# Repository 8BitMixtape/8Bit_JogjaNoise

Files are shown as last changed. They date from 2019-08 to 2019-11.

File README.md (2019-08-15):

# 8Bit NoiseBomb - Jogjarmageddon

8Bit Mixtape goes minimal stompbox style for simple NoiseBomb!!

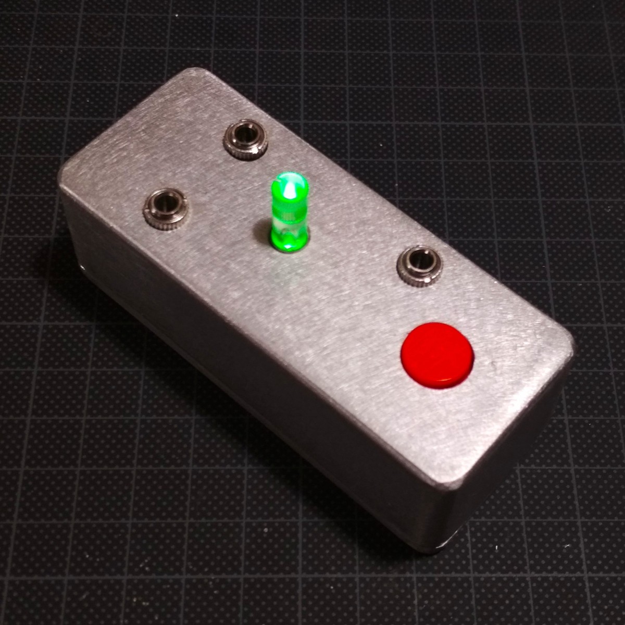
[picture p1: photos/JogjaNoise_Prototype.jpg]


It is a lo-fi 8Bit noise synthesizer based on the Arduino-compatible ATTINY85, featuring 1 Pot, 1 Button and a single LED inside the potentiometer shaft. Multiple NoiseBombs can be connected to each other using CV input/output and synced to other standard gear (KORG, Pocket Operators and more).

# Features

## New Bootloader for instant Noise

The key feature of the new 8Bit NoiseBomb is the easiness of uploading new codes using an audio communication protocol, means just playing a .wav sound file from your computer/smart phone (or walkman). Adjust volume to 50-70% if you encounter troubles during upload.

See more about this super powerful and easy-to-use TinyAudioBoot by Christoph Haberer here:
https://github.com/ChrisMicro/TinyAudioBoot

## Blinke Potentiometer

## 1 x CV input

## 1 Push Button

## diversity of Jacks 3.5 and 6.5 option

# PCB

We tried to create a PCB design that fits into a Hammond 1590A box, but also can be used stand-alone, and etched by hand single sided.

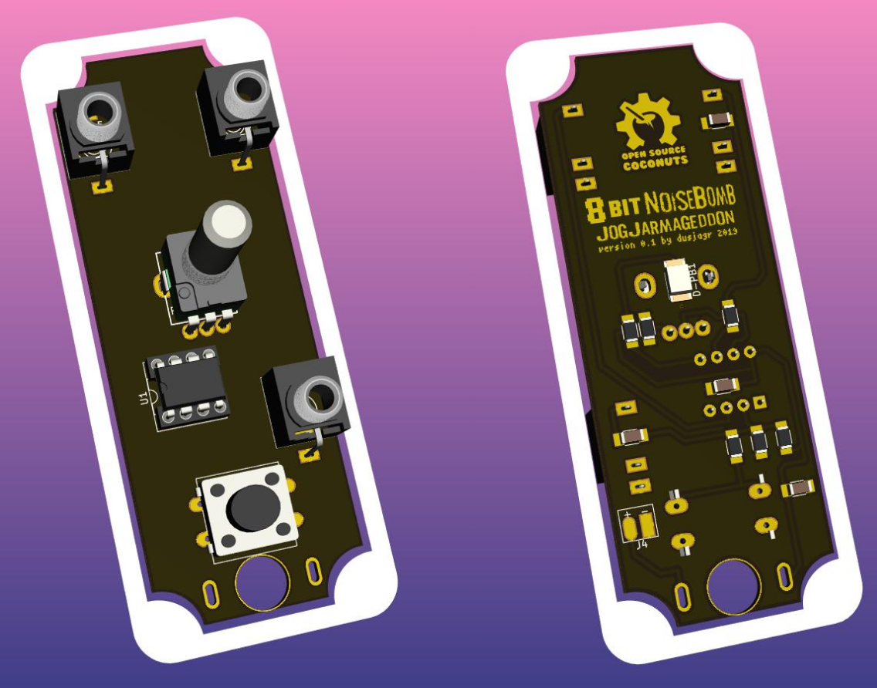
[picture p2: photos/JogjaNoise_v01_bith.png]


# Schematic

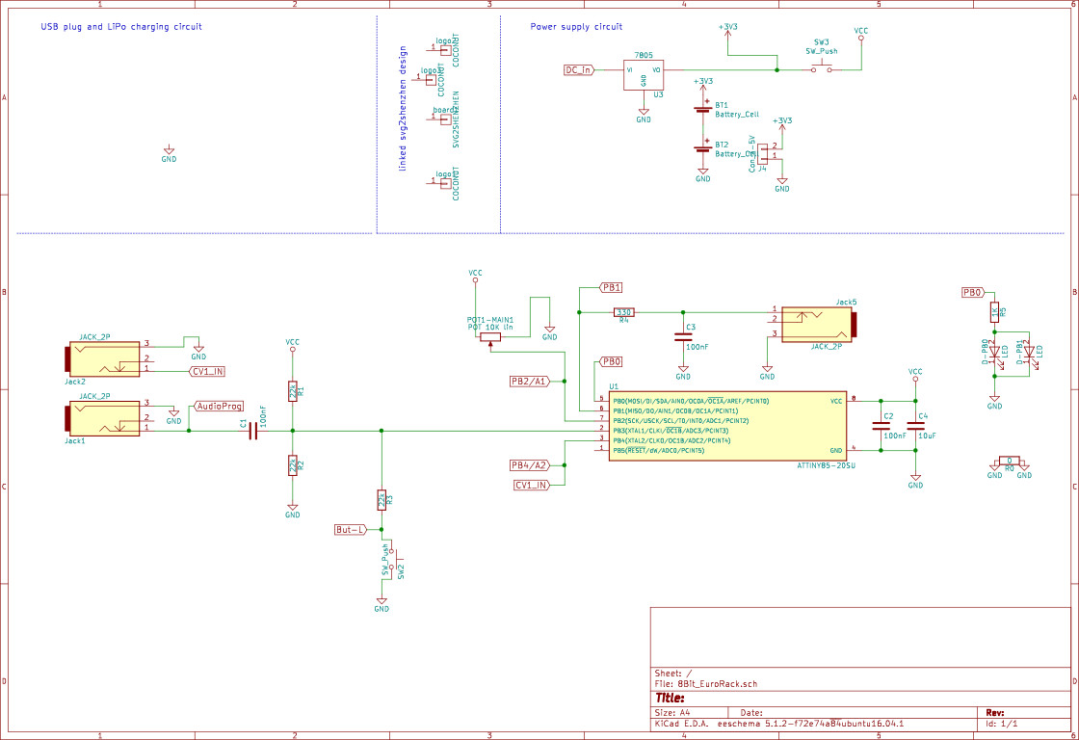
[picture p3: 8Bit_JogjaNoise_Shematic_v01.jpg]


# Sound / Noise Software

## Community contributions

Choose from a large collection of community contributed [Sequencers, Noise Generators & Synths](http://neo.8bitmixtape.cc/mixtape).

## Dedicated NoiseCodes

We have adapted other open source NoiseCodes to work on this little NoiseBomb, such as:

* Jogjarmageddon - based on [Mozenzeef's Jarmageddon](https://www.moffenzeefmodular.com/jarmaggeddon)
* QuantumNoise - based on [Alexander Zolotov's QuantumDJ](http://warmplace.ru/hard/qdj/)
* Adaptations from the [ATTINY PUNK CONSOLE by Steffen Koritsch](https://noisio.de/)
* Various Synths from the [8Bit Mixtape Community, especially by Budi Prakosa](http://neo.8bitmixtape.cc/mixtape)

## Write your own NoiseCode

Create your own custom synthesizers or filter using the popular Arduino IDE platform. Many examples help you to learn about DDS (Direct Digital Synthesis) using the 8Bit microcontroller ATTINY85.

Install the 8Bit Mixtape hardware in your Arduino IDE following the [instruction from the 8Bit Mixtape wiki](http://wiki.8bitmixtape.cc/)

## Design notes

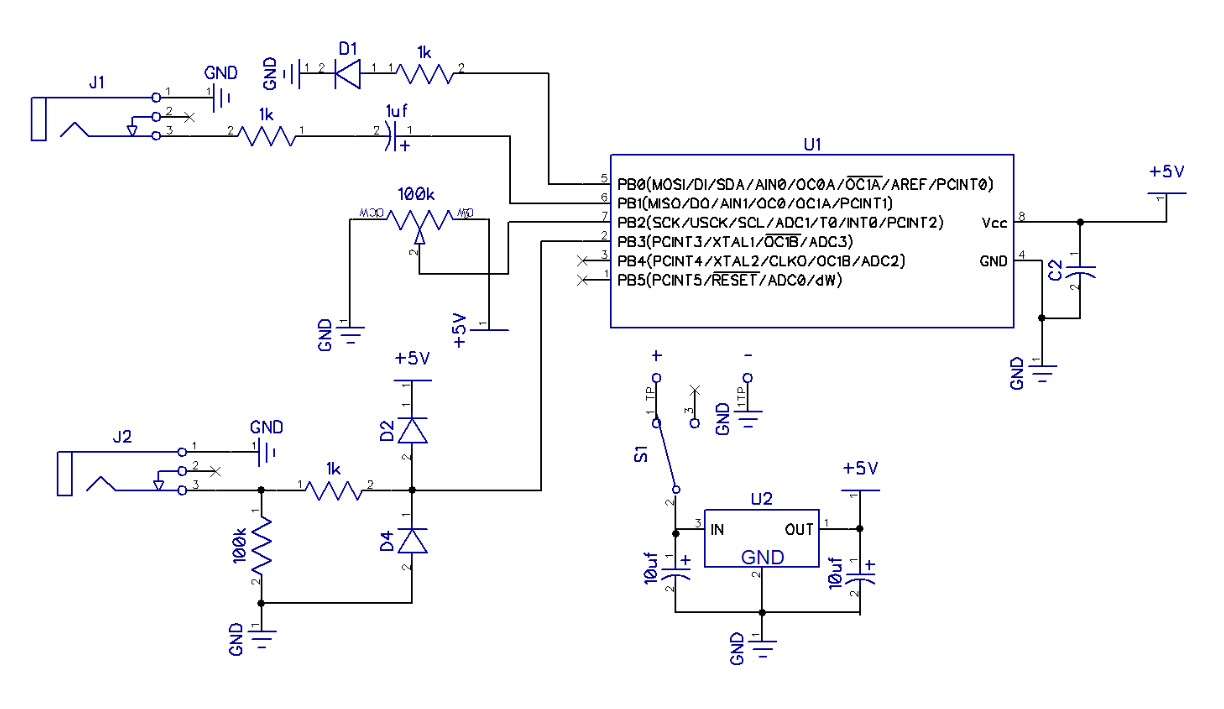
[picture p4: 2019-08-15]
photos/jarmageddon_schematics.png

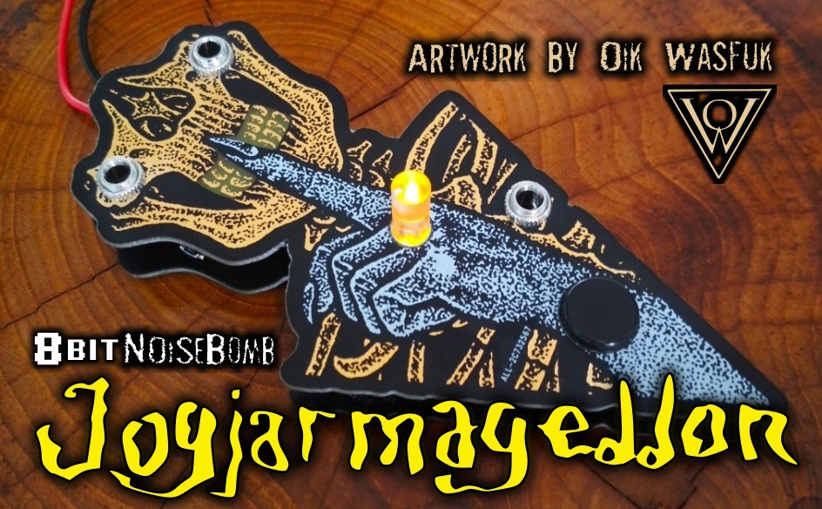
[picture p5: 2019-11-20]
photos/Jogjarmageddon_Product.jpg

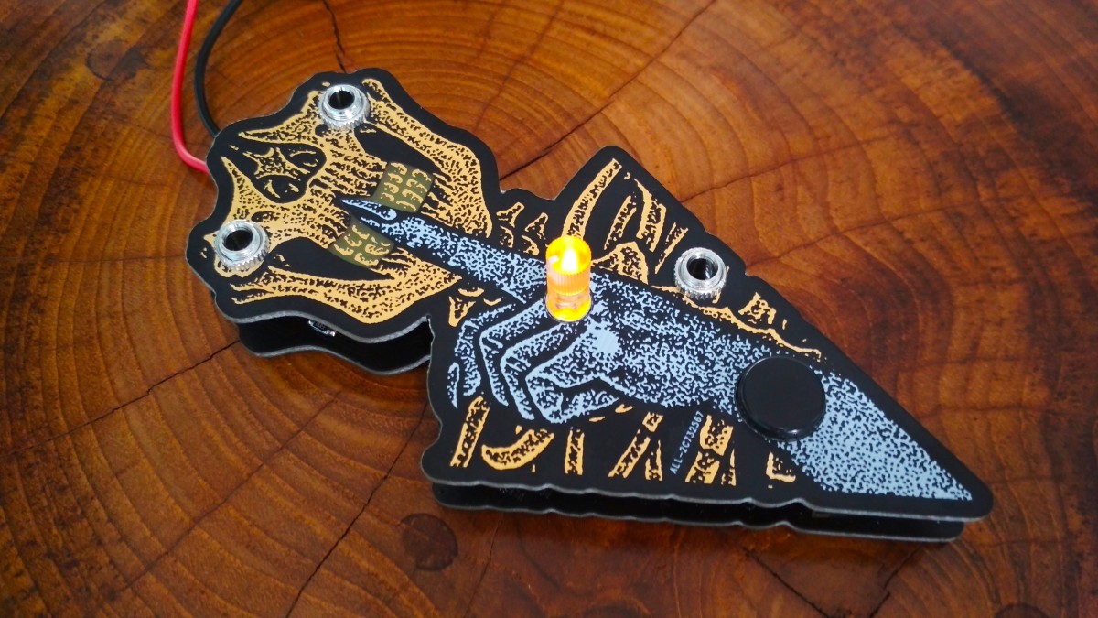
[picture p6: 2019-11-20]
photos/NoiseBomb_Oik_side.jpg

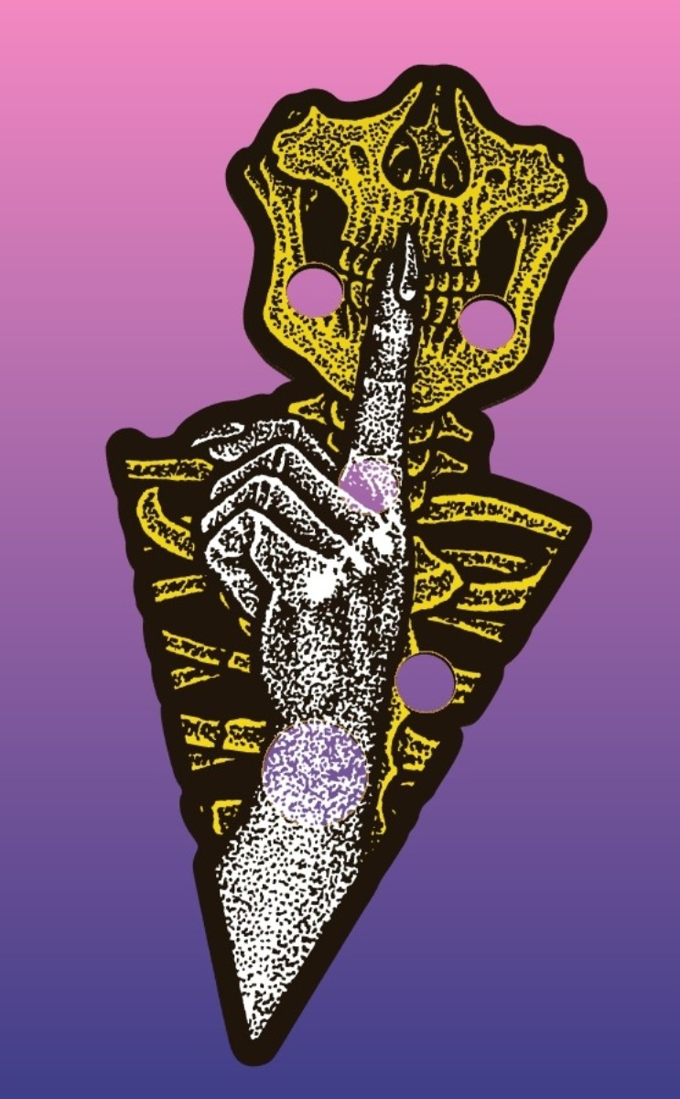
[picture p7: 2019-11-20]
photos/Jogjarmageddon_pcb.jpg

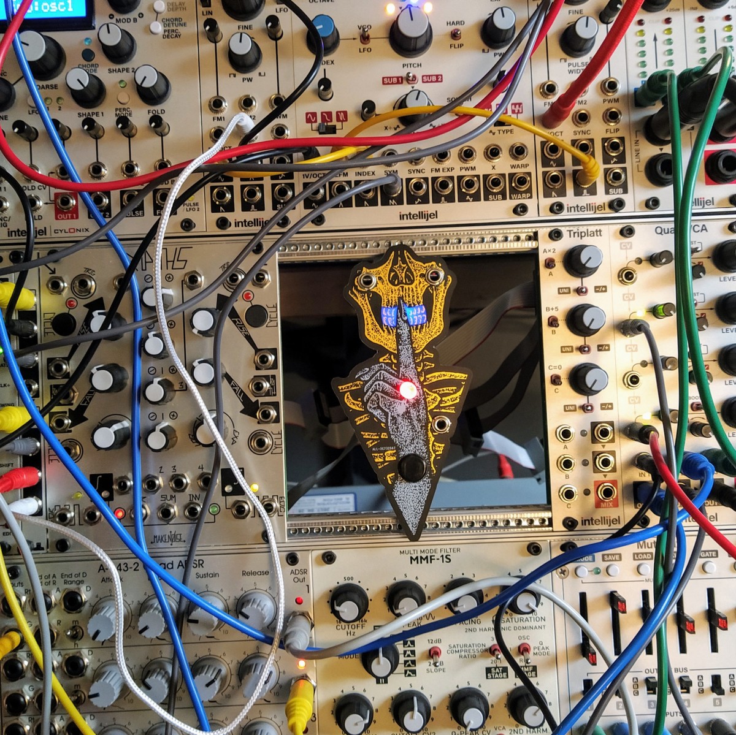
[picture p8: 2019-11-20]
photos/Jogjarmageddon_in_modular.jpg

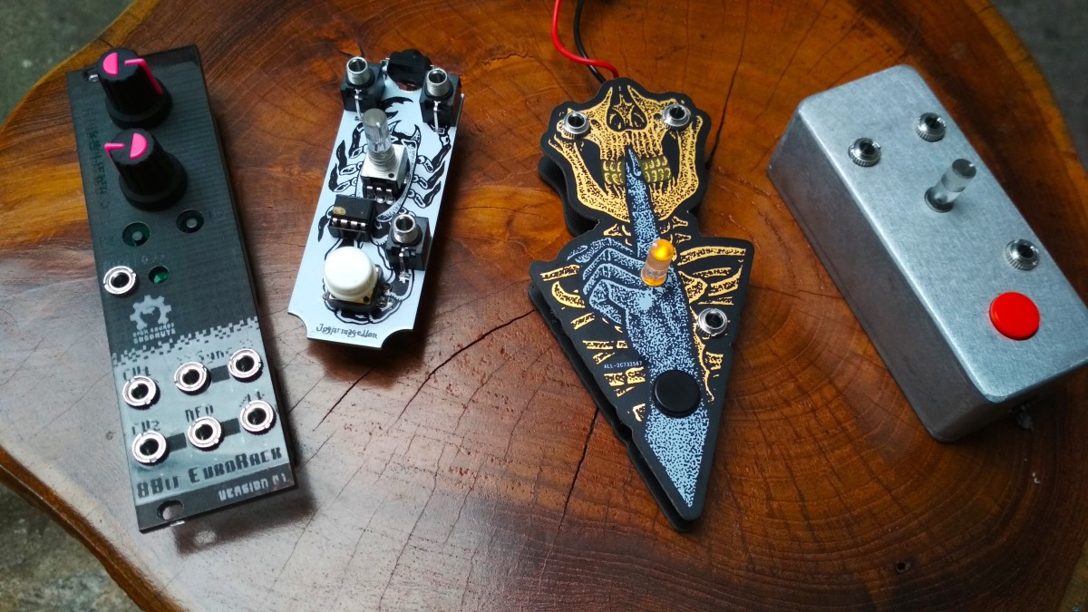
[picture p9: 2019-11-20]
photos/JogjaNoise_NewFamily_8BitMixtape.jpg

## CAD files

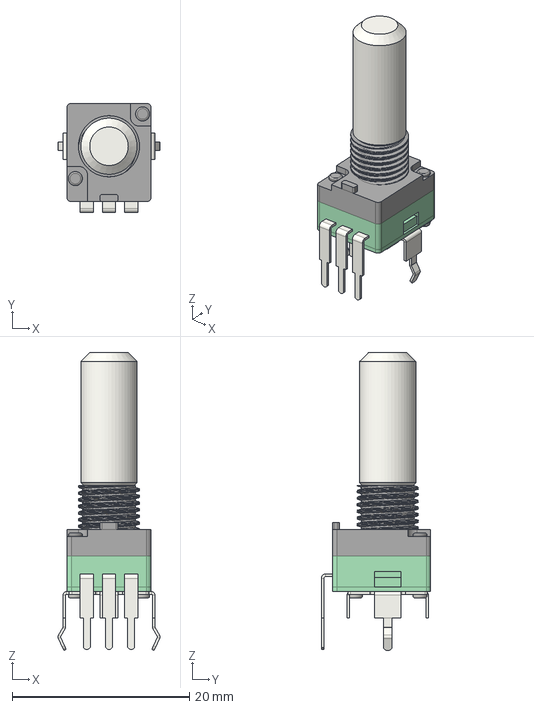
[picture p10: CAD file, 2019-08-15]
KiCAD/3d_models/ALPHA-RD901F-40.step
11.5 x 12.4 x 33.6 mm

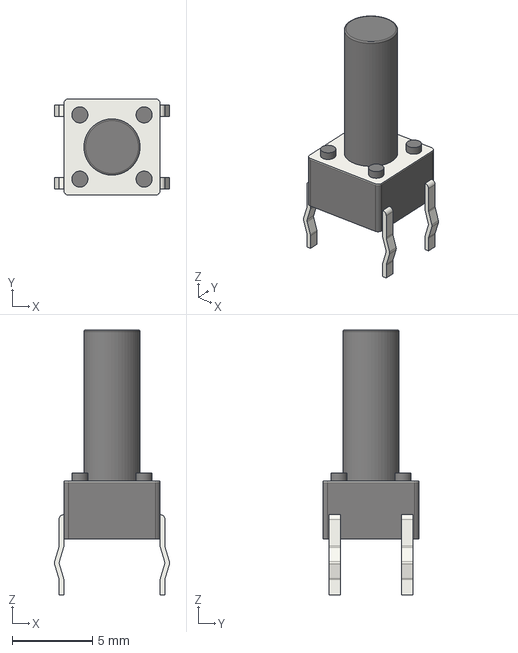
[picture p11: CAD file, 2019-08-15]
KiCAD/3d_models/SW_PUSH_6mm_H13mm.step
7.17 x 6.00 x 16.5 mm

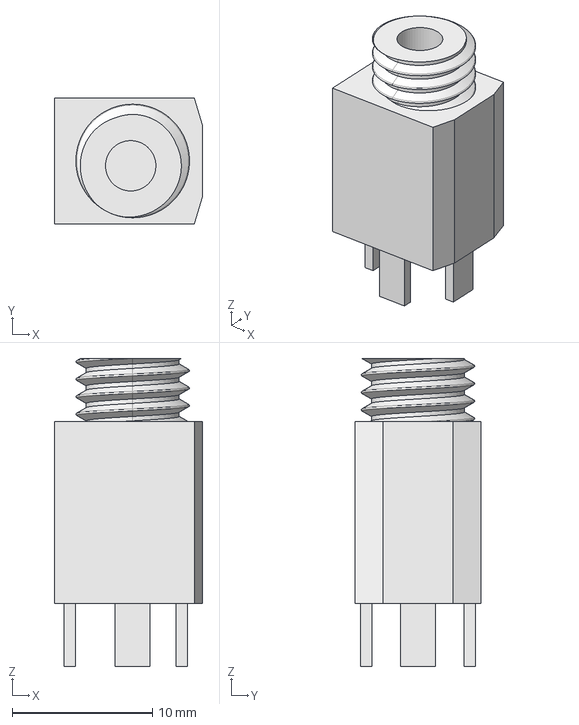
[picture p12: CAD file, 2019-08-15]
KiCAD/3d_models/PJ3410.step
10.6 x 9.00 x 22.0 mm

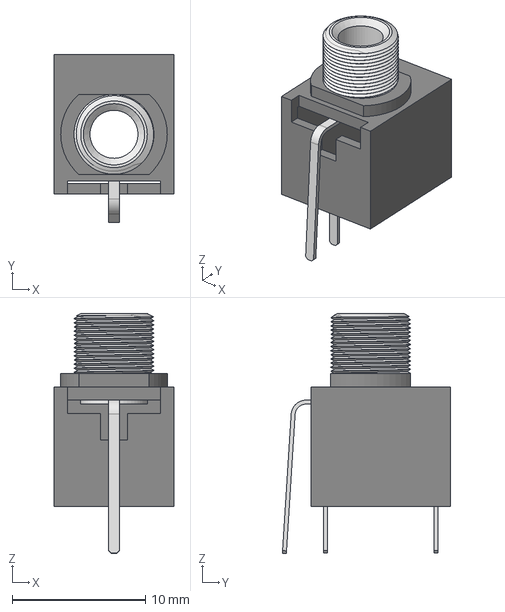
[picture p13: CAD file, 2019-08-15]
KiCAD/3d_models/PJ301M-12.step
9.00 x 12.6 x 18.0 mm

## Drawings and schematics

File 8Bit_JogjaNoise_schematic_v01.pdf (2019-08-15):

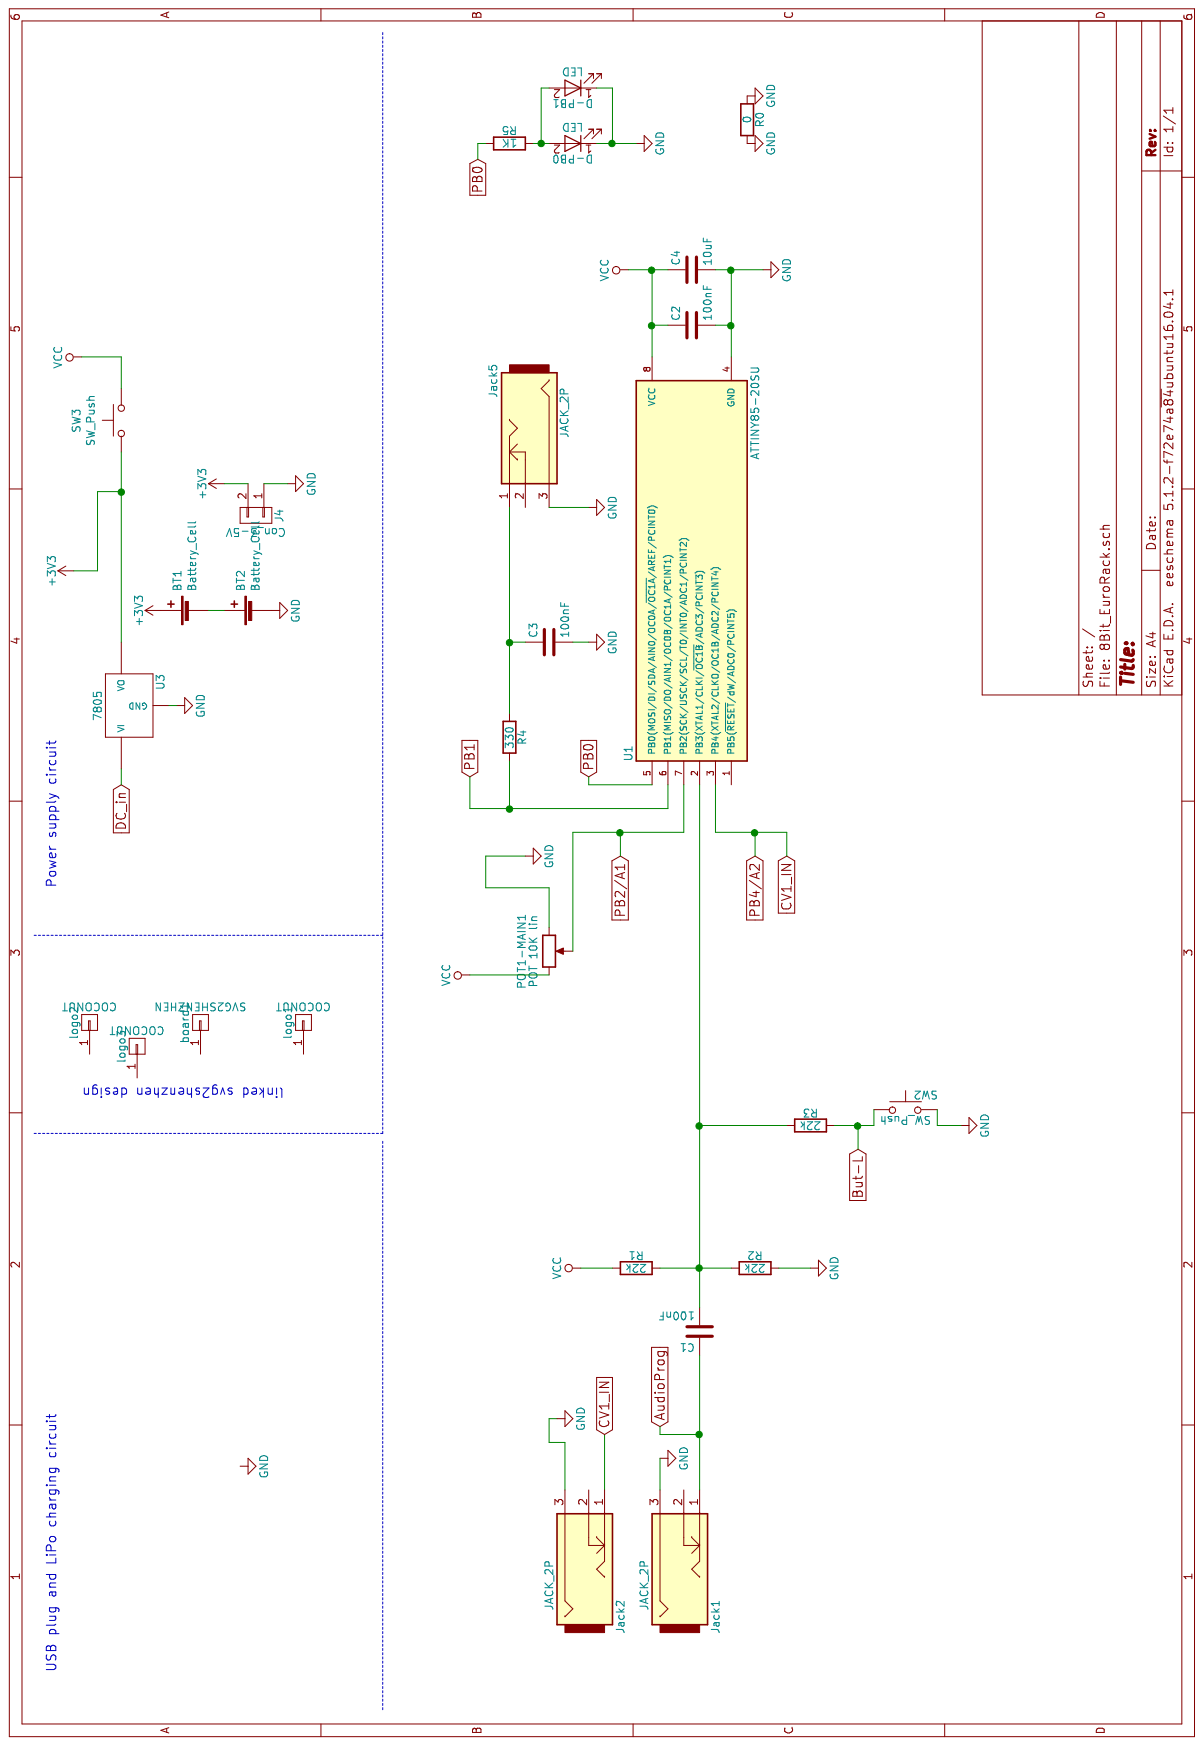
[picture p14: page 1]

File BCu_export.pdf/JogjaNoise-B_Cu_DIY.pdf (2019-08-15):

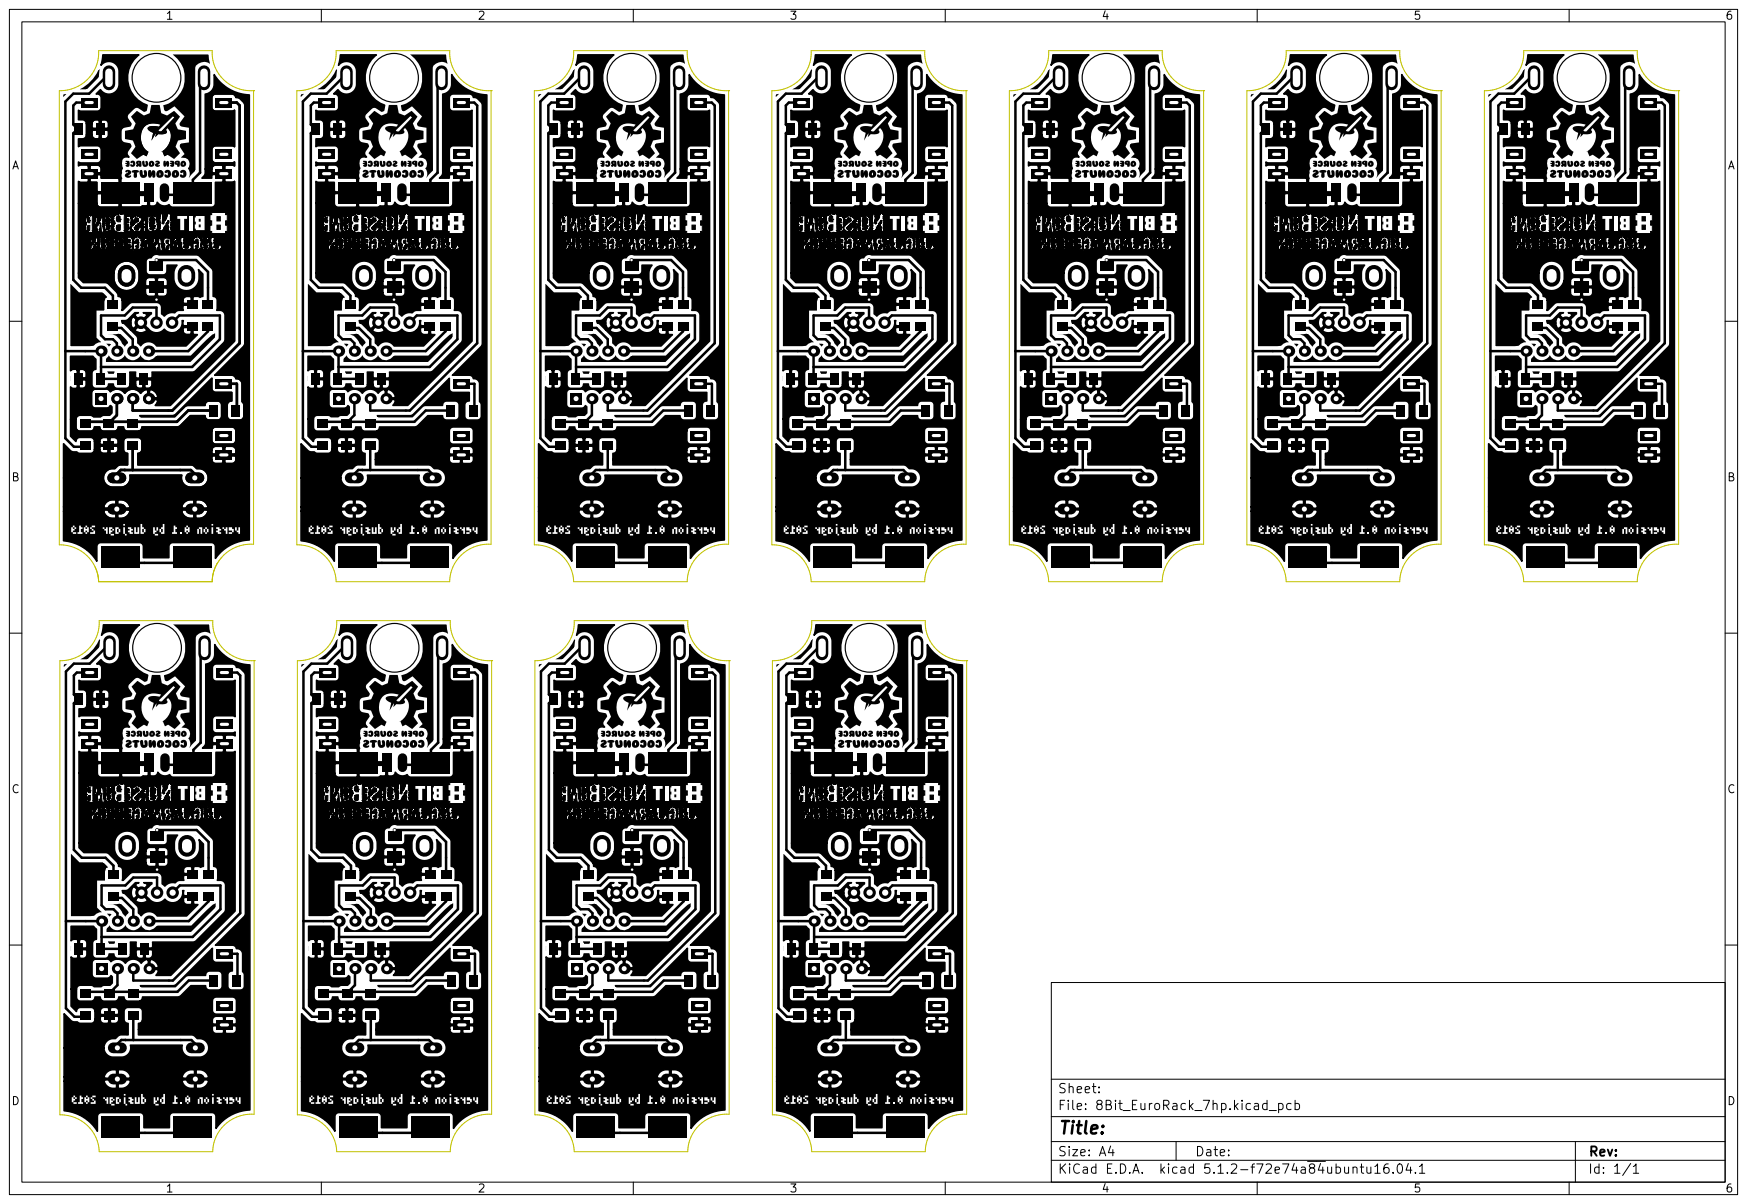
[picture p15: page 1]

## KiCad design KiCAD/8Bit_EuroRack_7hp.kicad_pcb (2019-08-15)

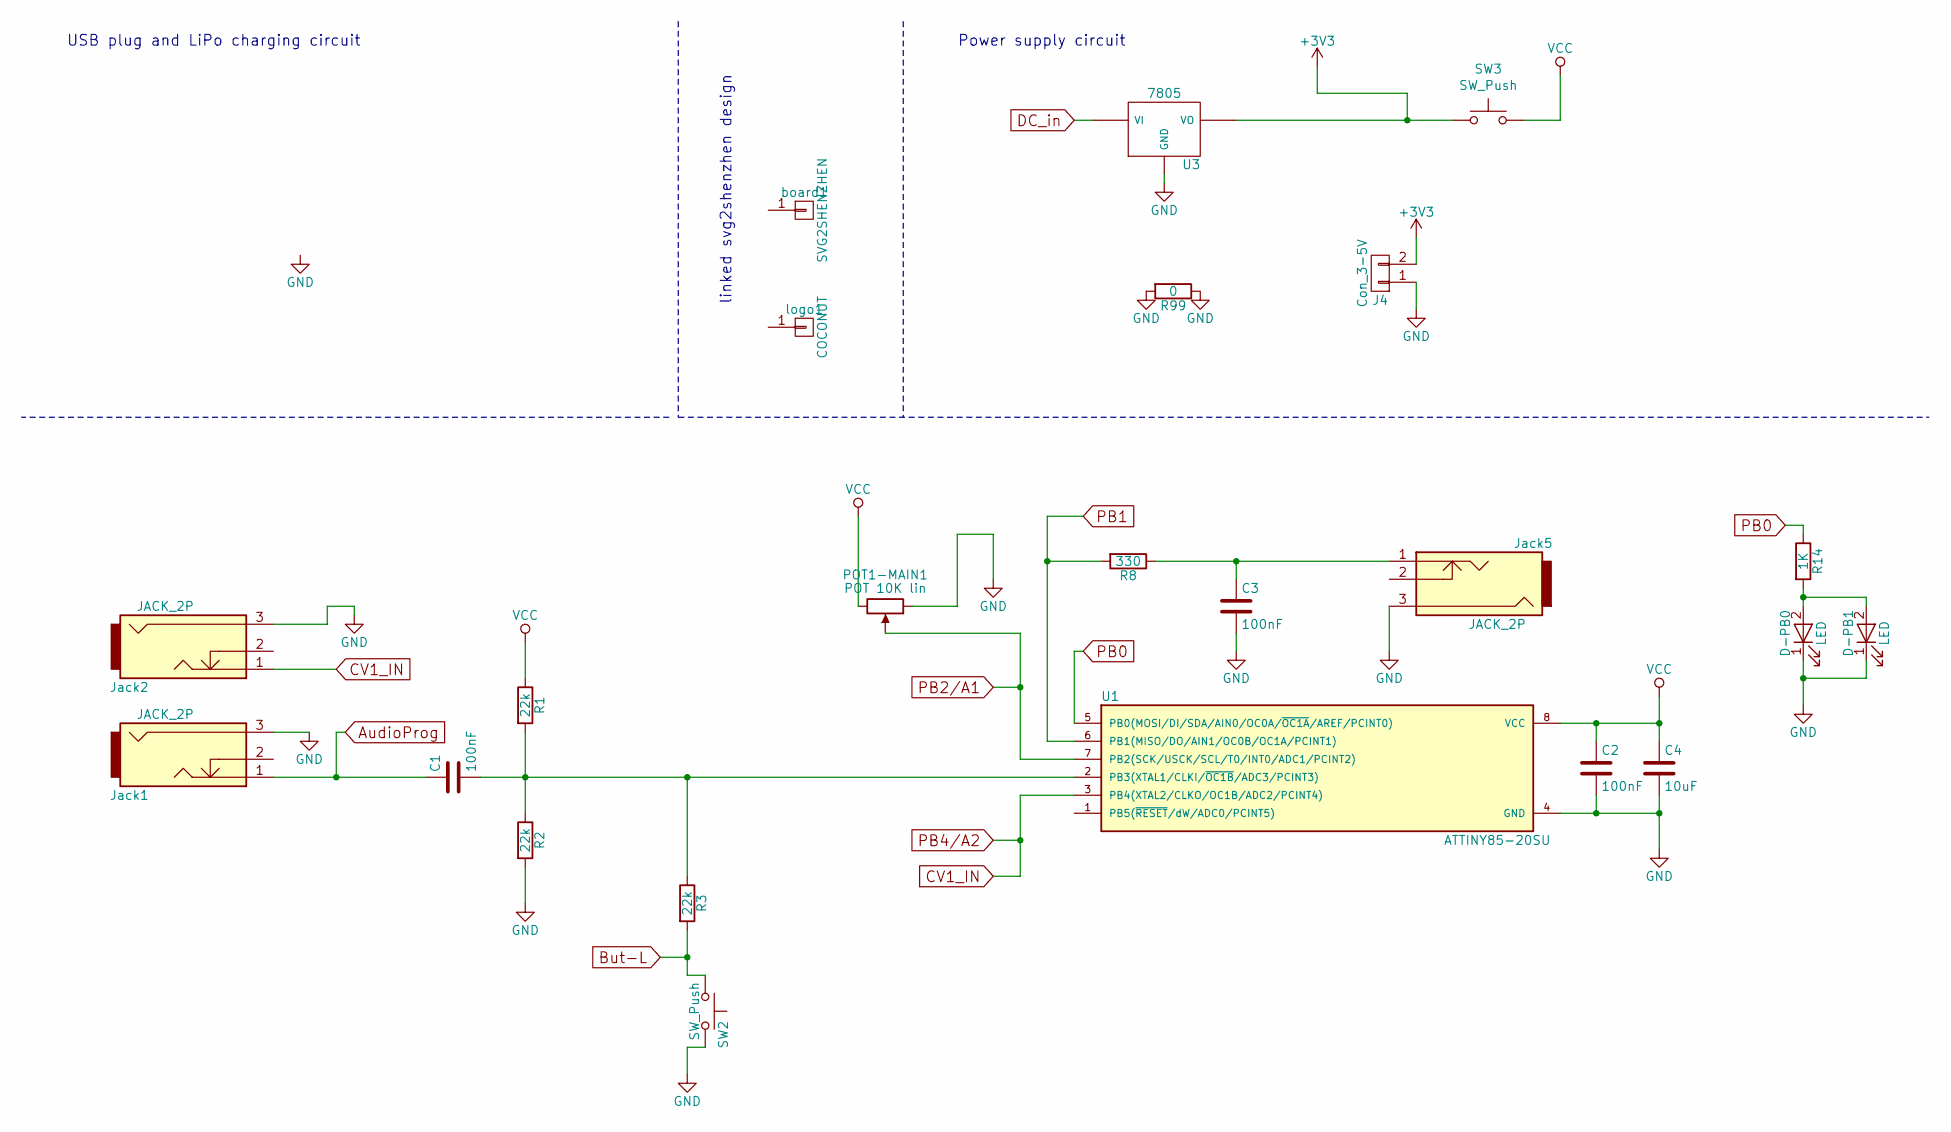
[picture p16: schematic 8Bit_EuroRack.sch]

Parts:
C1, C2, C3: 100nF; C_1206_3d
C4: 10uF; C_1206_3d
D-PB0, D-PB1: LED; LED_PLCC_2835_Handsoldering
J4: Con_3-5V; Bat_connector_SMD
Jack1, Jack2, Jack5: JACK_2P; PJ301M-12_dusjagr_3d
POT1-MAIN1: POT 10K lin; RD901F-ALPHA-3D
R1, R2, R3: 22k; R_1206_3d
R8: 330; R_1206_3d
R14: 1K; R_1206_3d
R99: 0; R_1206_3d
SW2: SW_Push; SW_PUSH-12mm_3D_new
SW3: SW_Push; Push_SWITCH_hole
U1: ATTINY85-20SU; DIP-8_Attiny_with_Socket_3d
U3: 7805; TO-252-3_TabPin2
board1: SVG2SHENZHEN; 8Bit_YogyaNoise
logo1: COCONUT; Coconut_logo

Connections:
+3V3: J4.2, SW3.1, U3.3 (VO)
AudioProg: C1.1, Jack1.1
But-L: R3.2, SW2.1
CV1_IN: Jack2.1, U1.3 (PB4(XTAL2/CLKO/OC1B/ADC2/PCINT4))
GND: C2.2, C3.2, C4.2, D-PB0.1 (K), D-PB1.1 (K), J4.1, Jack1.3, Jack2.3, Jack5.3, POT1-MAIN1.1, R2.2, R99.1, R99.2, SW2.2, U1.4 (GND), U3.2 (GND)
unnamed: C1.2, R1.2, R2.1, R3.1, U1.2 (PB3(XTAL1/CLKI/~OC1B~/ADC3/PCINT3))
unnamed: C3.1, Jack5.1, R8.1
unnamed: D-PB0.2 (A), D-PB1.2 (A), R14.2
PB0: R14.1, U1.5 (PB0(MOSI/DI/SDA/AIN0/OC0A/~OC1A~/AREF/P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)
PB1: R8.2, U1.6 (PB1(MISO/DO/AIN1/OC0B/OC1A/PCINT1))
PB2/A1: POT1-MAIN1.2, U1.7 (PB2(SCK/USCK/SCL/T0/INT0/ADC1/PCINT2))
VCC: C2.1, C4.1, POT1-MAIN1.3, R1.1, SW3.2, U1.8 (VCC)

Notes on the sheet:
USB plug and LiPo charging circuit
linked svg2shenzhen design
Power supply circuit

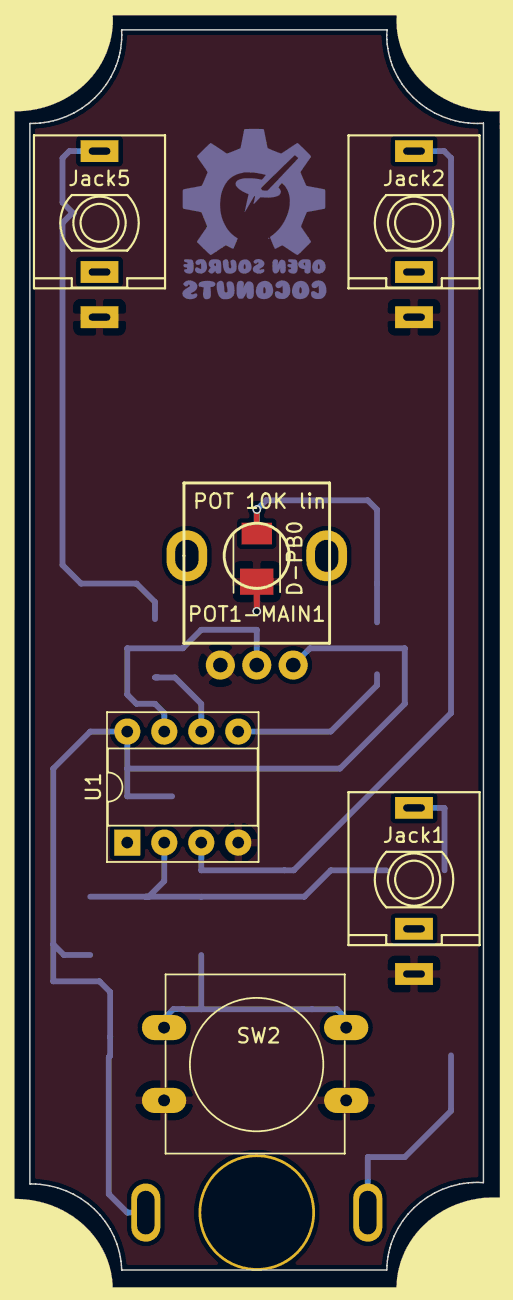
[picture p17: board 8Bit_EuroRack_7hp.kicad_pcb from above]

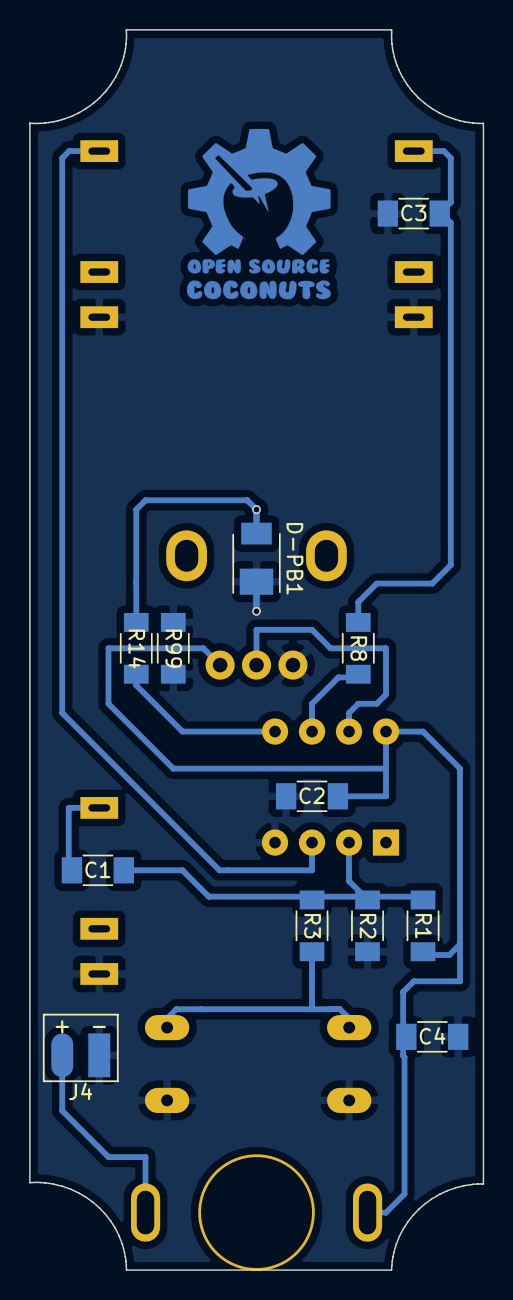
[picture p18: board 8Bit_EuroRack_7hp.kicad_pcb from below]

Board: 2 copper layers, 31.1 x 85.1 mm, 23 parts (14 on the bottom side), 12 nets.

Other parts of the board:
Ref**: Val**; NoiseBomb_logo

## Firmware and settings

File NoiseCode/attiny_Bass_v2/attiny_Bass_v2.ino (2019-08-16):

// ######################## Clock 16 Mhz intern ############################################

#include <avr/pgmspace.h>
#include "neolib.h"

uint8_t sync = 0;
uint8_t wave = 1;

bool full = true;

uint8_t uSteps = 192;                                // microsteps in one octave
unsigned int Acc = 255;
unsigned int Acc2 = 255;
const uint8_t vol = 255;
unsigned int note = 214;
unsigned int baseNote = 288;
unsigned int note2, type;
bool gateOpen;
uint8_t  LedPosition   = 0;

//


const unsigned int tunes1345steps[] PROGMEM = {
  54, 54, 54, 54, 54, 55, 55, 55, 55, 55, 56, 56, 56, 56, 56, 57,   // tempered 12 tune steps on left column
  57, 57, 57, 57, 58, 58, 58, 58, 58, 59, 59, 59, 59, 59, 60, 60,    // others are used as microsteps for detune
  60, 60, 61, 61, 61, 61, 61, 62, 62, 62, 62, 63, 63, 63, 63, 63,
  64, 64, 64, 64, 65, 65, 65, 65, 66, 66, 66, 66, 67, 67, 67, 67,
  68, 68, 68, 68, 68, 69, 69, 69, 69, 70, 70, 70, 70, 71, 71, 71,
  72, 72, 72, 72, 73, 73, 73, 73, 74, 74, 74, 74, 75, 75, 75, 76,
  76, 76, 76, 77, 77, 77, 77, 78, 78, 78, 79, 79, 79, 79, 80, 80,
  80, 81, 81, 81, 81, 82, 82, 82, 83, 83, 83, 84, 84, 84, 84, 85,
  85, 85, 86, 86, 86, 87, 87, 87, 88, 88, 88, 89, 89, 89, 89, 90,
  90, 90, 91, 91, 91, 92, 92, 92, 93, 93, 93, 94, 94, 94, 95, 95,
  95, 96, 96, 97, 97, 97, 98, 98, 98, 99, 99, 99, 100, 100, 100, 101,
  101, 102, 102, 102, 103, 103, 103, 104, 104, 104, 105, 105, 106, 106, 106, 107,   // here the first octave ends
  107, 108, 108, 108, 109, 109, 110, 110, 110, 111, 111, 112, 112, 112, 113, 113,
  114, 114, 114, 115, 115, 116, 116, 116, 117, 117, 118, 118, 119, 119, 119, 120,
  120, 121, 121, 122, 122, 122, 123, 123, 124, 124, 125, 125, 126, 126, 127, 127,
  127, 128, 128, 129, 129, 130, 130, 131, 131, 132, 132, 133, 133, 134, 134, 135,
  135, 136, 136, 136, 137, 137, 138, 138, 139, 139, 140, 140, 141, 142, 142, 143,
  143, 144, 144, 145, 145, 146, 146, 147, 147, 148, 148, 149, 149, 150, 150, 151,
  152, 152, 153, 153, 154, 154, 155, 155, 156, 157, 157, 158, 158, 159, 159, 160,
  161, 161, 162, 162, 163, 163, 164, 165, 165, 166, 166, 167, 168, 168, 169, 169,
  170, 171, 171, 172, 173, 173, 174, 174, 175, 176, 176, 177, 178, 178, 179, 180,
  180, 181, 182, 182, 183, 184, 184, 185, 186, 186, 187, 188, 188, 189, 190, 190,
  191, 192, 192, 193, 194, 194, 195, 196, 197, 197, 198, 199, 199, 200, 201, 202,
  202, 203, 204, 204, 205, 206, 207, 207, 208, 209, 210, 210, 211, 212, 213, 214,
  214, 215, 216, 217, 217, 218, 219, 220, 221, 221, 222, 223, 224, 225, 225, 226,
  227, 228, 229, 230, 230, 231, 232, 233, 234, 235, 235, 236, 237, 238, 239, 240,
  241, 241, 242, 243, 244, 245, 246, 247, 248, 249, 249, 250, 251, 252, 253, 254,
  255, 256, 257, 258, 259, 260, 260, 261, 262, 263, 264, 265, 266, 267, 268, 269,
  270, 271, 272, 273, 274, 275, 276, 277, 278, 279, 280, 281, 282, 283, 284, 285,
  286, 287, 288, 289, 290, 291, 292, 293, 294, 296, 297, 298, 299, 300, 301, 302,
  303, 304, 305, 306, 308, 309, 310, 311, 312, 313, 314, 315, 317, 318, 319, 320,
  321, 322, 323, 325, 326, 327, 328, 329, 331, 332, 333, 334, 335, 337, 338, 339,
  340, 341, 343, 344, 345, 346, 348, 349, 350, 351, 353, 354, 355, 357, 358, 359,
  360, 362, 363, 364, 366, 367, 368, 370, 371, 372, 374, 375, 376, 378, 379, 381,
  382, 383, 385, 386, 387, 389, 390, 392, 393, 394, 396, 397, 399, 400, 402, 403,
  405, 406, 408, 409, 410, 412, 413, 415, 416, 418, 419, 421, 423, 424, 426, 427,
  429, 430, 432, 433, 435, 436, 438, 440, 441, 443, 444, 446, 448, 449, 451, 452,
  454, 456, 457, 459, 461, 462, 464, 466, 467, 469, 471, 473, 474, 476, 478, 479,
  481, 483, 485, 486, 488, 490, 492, 493, 495, 497, 499, 501, 502, 504, 506, 508,
  510, 512, 513, 515, 517, 519, 521, 523, 525, 527, 528, 530, 532, 534, 536, 538,
  540, 542, 544, 546, 548, 550, 552, 554, 556, 558, 560, 562, 564, 566, 568, 570,
  572, 574, 576, 578, 580, 583, 585, 587, 589, 591, 593, 595, 598, 600, 602, 604,
  606, 608, 611, 613, 615, 617, 619, 622, 624, 626, 628, 631, 633, 635, 638, 640,
  642, 645, 647, 649, 652, 654, 656, 659, 661, 663, 666, 668, 671, 673, 676, 678,
  680, 683, 685, 688, 690, 693, 695, 698, 700, 703, 705, 708, 711, 713, 716, 718,
  721, 724, 726, 729, 731, 734, 737, 739, 742, 745, 747, 750, 753, 756, 758, 761,
  764, 767, 769, 772, 775, 778, 780, 783, 786, 789, 792, 795, 798, 800, 803, 806,
  809, 812, 815, 818, 821, 824, 827, 830, 833, 836, 839, 842, 845, 848, 851, 854,
  857, 860, 864, 867, 870, 873, 876, 879, 882, 886, 889, 892, 895, 898, 902, 905,
  908, 912, 915, 918, 921, 925, 928, 932, 935, 938, 942, 945, 948, 952, 955, 959,
  962, 966, 969, 973, 976, 980, 983, 987, 990, 994, 998, 1001, 1005, 1009, 1012, 1016,
  1020, 1023, 1027, 1031, 1034, 1038, 1042, 1046, 1049, 1053, 1057, 1061, 1065, 1068, 1072, 1076,
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
};

const byte sine256[] PROGMEM = { // sine wavetable
  0, 0, 0, 0, 0, 0, 1, 1, 1, 2, 2, 3, 4, 5, 5, 6, 7, 9, 10, 11, 12, 14, 15, 17, 18, 20, 21, 23, 25, 27, 29, 31, 33, 35, 37, 40, 42, 44, 47, 49, 52, 54, 57, 59, 62, 65, 67, 70, 73, 76, 79, 82, 85, 88, 90, 93, 97, 100, 103, 106, 109, 112, 115, 118, 121, 124, 128,
  128, 131, 134, 137, 140, 143, 146, 149, 152, 155, 158, 162, 165, 167, 170, 173, 176, 179, 182, 185, 188, 190, 193, 196, 198, 201, 203, 206, 208, 211, 213, 215, 218, 220, 222, 224, 226, 228, 230, 232, 234, 235, 237, 238, 240, 241, 243, 244, 245, 246,
  248, 249, 250, 250, 251, 252, 253, 253, 254, 254, 254, 255, 255, 255, 255, 255, 255, 255, 254, 254, 254, 253, 253, 252, 251, 250, 250, 249, 248, 246, 245, 244, 243, 241, 240, 238, 237, 235, 234, 232, 230, 228, 226, 224, 222, 220, 218, 215, 213, 211,
  208, 206, 203, 201, 198, 196, 193, 190, 188, 185, 182, 179, 176, 173, 170, 167, 165, 162, 158, 155, 152, 149, 146, 143, 140, 137, 134, 131, 128, 124, 121, 118, 115, 112, 109, 106, 103, 100, 97, 93, 90, 88, 85, 82, 79, 76, 73, 70, 67, 65,
  62, 59, 57, 54, 52, 49, 47, 44, 42, 40, 37, 35, 33, 31, 29, 27, 25, 23, 21, 20, 18, 17, 15, 14, 12, 11, 10, 9, 7, 6, 5, 5, 4, 3, 2, 2, 1, 1, 1, 0
};



void setup() {
  
  OSCCAL += 3;                            // Oscillator calibration

  // Enable 64 MHz PLL and use as source for Timer1
  PLLCSR = 1 << PCKE | 1 << PLLE;

  // Set up Timer/Counter1 for PWM output
  TIMSK = 0;                                          // Timer interrupts OFF
  TCCR1 = 1 << PWM1A | 2 << COM1A0 | 1 << CS10;       // PWM OCR1A, clear on match, 1:1 prescale
  pinMode(1, OUTPUT);                                 // Enable PWM output pin

  // Set up Timer/Counter0 for interrupt to output samples.
  TCCR0A = 3 << WGM00;                                // Fast PWM
  TCCR0B = 1 << WGM02 | 2 << CS00;                    // 1/8 prescale
  TIMSK = 1 << OCIE0A;                                // Enable compare match, disable overflow
  OCR0A = 199;                                         // Divide by 400
  pinMode(0, OUTPUT);
  neobegin();
  setColorAllPixel(colorWheel(220));
  pixels.show();
}

void loop() {
    
  uint8_t b = wasButtonPressed();
  
  if( b == BUTTON_LEFT                )   LedPosition--   ;
  if( b == BUTTON_RIGHT               )   LedPosition++   ;  

  LedPosition   &= 0b00000011; // prevent out of range
  
  gateOpen = 1;
  int16_t lp = getPoti( POTI_RIGHT );        // range 0..1023
  int16_t rp = getPoti( POTI_LEFT );    // range 0..255

  //setColorAllPixel(colorWheel(220));
  //pixels.setPixelColor( 2, COLOR_GREEN );
  //pixels.show();

  baseNote = (map(lp, 0, 1023, 12, 72) << 4) + uSteps;
  note = pgm_read_word(&tunes1345steps[baseNote]);

  int detune = map(rp, 1023, 0, 0, uSteps);
  if (detune == 0) {
    note2 = note >> 1;
  } else {
    note2 = pgm_read_word(&tunes1345steps[baseNote + detune - uSteps]);
  }

  type = LedPosition;

}


ISR(TIMER0_COMPA_vect) {

  if (gateOpen) {
 
    Acc = Acc + note;
    Acc2 = Acc2 + note2;


    switch (type) {

      case 0:                                         // Square

        int temp, temp2;
        OCR1A = ((((Acc >> 8) & 0x80) + ((Acc2 >> 8) & 0x80)) * vol) >> 8;
        break;

      case 1:                                         // Ramp Up

        OCR1A = (((Acc >> 9) + (Acc2 >> 9)) * vol) >> 8;
        break;

      case 2:                                         // Triangle

        signed char Temp, Mask, Temp2, Mask2;
        Temp = Acc >> 8;
        Mask = Temp >> 7;
        Temp2 = Acc2 >> 8;
        Mask2 = Temp2 >> 7;
        OCR1A = (((Temp ^ Mask) + (Temp2 ^ Mask2)) * vol) >> 8 ;
        break;

      case 3:                                         // Sinus

        OCR1A = (((pgm_read_byte(&sine256[Acc >> 8]) + pgm_read_byte(&sine256[Acc2 >> 8])) >> 1) * vol) >> 8;
        break;

    }
  }
}

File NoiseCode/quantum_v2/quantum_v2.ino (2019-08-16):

#include <Arduino.h>
#line 1 "/Users/xcorex/Documents/Arduino/quantumNEODJ/quantumNEODJ.ino"
#line 1 "/Users/xcorex/Documents/Arduino/quantumNEODJ/quantumNEODJ.ino"
/*
    main.cpp
    Quantum DJ
    
    [ MIT license ]

    Copyright (c) 2015 - 2017, Alexander Zolotov <nightradio@gmail.com>
    www.warmplace.ru
    
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
    THE SOFTWARE IS PROVIDED "AS IS", WITHOUT WARRANTY OF ANY KIND, EXPRESS OR 
    IMPLIED, INCLUDING BUT NOT LIMITED TO THE WARRANTIES OF MERCHANTABILITY, 
    FITNESS FOR A PARTICULAR PURPOSE AND NONINFRINGEMENT. IN NO EVENT SHALL THE
    AUTHORS OR COPYRIGHT HOLDERS BE LIABLE FOR ANY CLAIM, DAMAGES OR OTHER 
    LIABILITY, WHETHER IN AN ACTION OF CONTRACT, TORT OR OTHERWISE, ARISING 
    FROM, OUT OF OR IN CONNECTION WITH THE SOFTWARE OR THE USE OR OTHER DEALINGS
    IN THE SOFTWARE.
*/

#include <WS2812.h>

#define LEDCount 8
#define outputPin 3

WS2812 LED(LEDCount);
cRGB value;

#include <avr/io.h>
#include <util/delay.h>
#include <avr/interrupt.h>
#include <avr/pgmspace.h>
#include <avr/power.h>
#include "neo_lib.h"

#ifdef PROGMEM
#undef PROGMEM
#define PROGMEM __attribute__((section(".progmem.data")))
#endif


#define CLOCK_PRESCALER 3
#define F_CPU ( 8000000UL >> CLOCK_PRESCALER )

//Half of sinus:
static const unsigned char g_hsin_tab[ 256 ] PROGMEM =
{
  0, 3, 6, 9, 12, 15, 18, 21, 25, 28, 31, 34, 37, 40, 43, 46,
  49, 52, 56, 59, 62, 65, 68, 71, 74, 77, 80, 83, 86, 89, 92, 95,
  97, 100, 103, 106, 109, 112, 115, 117, 120, 123, 126, 128, 131, 134, 136, 139,
  142, 144, 147, 149, 152, 154, 157, 159, 162, 164, 167, 169, 171, 174, 176, 178,
  180, 183, 185, 187, 189, 191, 193, 195, 197, 199, 201, 203, 205, 207, 209, 211,
  212, 214, 216, 217, 219, 221, 222, 224, 225, 227, 228, 229, 231, 232, 233, 235,
  236, 237, 238, 239, 240, 242, 243, 243, 244, 245, 246, 247, 248, 249, 249, 250,
  251, 251, 252, 252, 253, 253, 254, 254, 254, 255, 255, 255, 255, 255, 255, 255,
  255, 255, 255, 255, 255, 255, 255, 255, 254, 254, 254, 253, 253, 252, 252, 251,
  251, 250, 249, 249, 248, 247, 246, 245, 245, 244, 243, 242, 241, 240, 238, 237,
  236, 235, 234, 232, 231, 230, 228, 227, 225, 224, 222, 221, 219, 218, 216, 214,
  213, 211, 209, 207, 205, 203, 201, 200, 198, 196, 194, 191, 189, 187, 185, 183,
  181, 179, 176, 174, 172, 169, 167, 165, 162, 160, 157, 155, 152, 150, 147, 145,
  142, 139, 137, 134, 131, 129, 126, 123, 120, 118, 115, 112, 109, 106, 104, 101,
  98, 95, 92, 89, 86, 83, 80, 77, 74, 71, 68, 65, 62, 59, 56, 53,
  50, 47, 44, 41, 37, 34, 31, 28, 25, 22, 19, 16, 12, 9, 6, 3
};

#line 74 "/Users/xcorex/Documents/Arduino/quantumNEODJ/quantumNEODJ.ino"
static int sin8( int phase );
#line 125 "/Users/xcorex/Documents/Arduino/quantumNEODJ/quantumNEODJ.ino"
static unsigned char get_options( void );
#line 139 "/Users/xcorex/Documents/Arduino/quantumNEODJ/quantumNEODJ.ino"
static int adc_read();
#line 151 "/Users/xcorex/Documents/Arduino/quantumNEODJ/quantumNEODJ.ino"
void adc_init();
#line 161 "/Users/xcorex/Documents/Arduino/quantumNEODJ/quantumNEODJ.ino"
void adc_start();
#line 165 "/Users/xcorex/Documents/Arduino/quantumNEODJ/quantumNEODJ.ino"
int main();
#line 74 "/Users/xcorex/Documents/Arduino/quantumNEODJ/quantumNEODJ.ino"
inline static int sin8( int phase )
{
  int rv;
  phase &= 511;
  if ( phase < 256 )
    rv = (int)pgm_read_byte( &g_hsin_tab[ phase & 255 ] );
  else
    rv = -(int)pgm_read_byte( &g_hsin_tab[ phase & 255 ] );
  return rv;
}


enum
{
  MODE_REPEAT = 0,
  MODE_REPEAT2,
  MODE_REPEAT3,
  MODE_REPEAT_MOD, //fast modulations
  MODE_REPEAT_MOD2, //stream modification: add
  MODE_REPEAT_MOD3, //stream modification: xor
  MODE_REPEAT_MOD4, //stream modification: mul
  MODE_WAVE,
  MODE_SINE,
  MODE_SINE2,
  MODE_MAX,
};

volatile uint16_t pot1; // 0...255
volatile uint16_t pot2; // 0...255
volatile uint16_t pot3; // 0...255

volatile uint8_t adc1 = _BV(ADLAR) | _BV(MUX0); //PB2-ADC1 pot1
volatile uint8_t adc2 = _BV(ADLAR) | _BV(MUX1); //PB4-ADC2 pot2
volatile uint8_t adc3 = _BV(ADLAR) | _BV(MUX0) | _BV(MUX1); //PB3-ADC3 pot3

#define ENTER_CRIT()    {byte volatile saved_sreg = SREG; cli()
#define LEAVE_CRIT()    SREG = saved_sreg;}


#define SLOWDOWN( len ) \
  { volatile char d = 0; for( volatile int dd = 0; dd < ( len ); dd++ ) d++; }

#define OUT( bit ) \
  { PORTB = ( PORTB & ~( 1 << output_bit_offset ) ) | ( bit ) << output_bit_offset; }

const int frame_len = 1024;
const int output_bit_offset = 1;

#define OPTION1_BIT ( 1 << 1 )
#define OPTION2_BIT ( 1 << 2 )

static unsigned char get_options( void )
{
  unsigned char rv = 0;
  uint8_t b = wasButtonPressed(pot3);

  if ( b == BUTTON_LEFT                )   rv |= 1;
  if ( b == BUTTON_RIGHT               )    rv |= 2;

  return rv;
}

#define adc_read_begin() ADCSRA |= ( 1 << ADSC )
#define adc_read_finished() ( ( ADCSRA & ( 1 << ADSC ) ) == 0 )
#define adc_get() ADC
static int adc_read() //Get 0...1023 or -512...+511 value from ADC channel
{
  return pot1 + pot2 + pot3;
  // start single convertion
  adc_read_begin();

  // wait for conversion to complete
  while ( !adc_read_finished() ) {}

  return adc_get();
}

void adc_init()
{
  ADCSRA |= _BV(ADIE); //adc interrupt enable
  ADCSRA |= _BV(ADEN); //adc enable
  ADCSRA |= _BV(ADATE); //auto trigger
  ADCSRA |= _BV(ADPS0) | _BV(ADPS1) | _BV(ADPS2); //prescale 128
  ADMUX  = adc3;
  ADCSRB = 0;
}

void adc_start()
{
  ADCSRA |= _BV(ADSC); //start adc conversion
}
int main()
{
  unsigned int stream = 0;
  unsigned int stream2 = 0;
  unsigned int emotion_counter = 0;

    clock_prescale_set(clock_div_16); //1MHZ LOFI
  adc_init();
  sei(); //enable global interrupt
  adc_start(); //start adc conversion

  //#ifdef CLOCK_PRESCALER
  //  CLKPR = 1 << CLKPCE;
  //  CLKPR = CLOCK_PRESCALER;
  //#endif

  DDRB = 1 << output_bit_offset; //Set Port B output bits
  PORTB = 0x00; //Turn all output pins on Port B off
  //  PORTB |= OPTION1_BIT | OPTION2_BIT; //Enable Pull-up resistors for the input pins
  int btn_timer = 0;
  int opt_btn = 0;
int ledRefresh = 0;
uint8_t fq = 1;
pinMode(0, OUTPUT);



  while ( 1 )
  {
    digitalWrite(0, HIGH);
    btn_timer++;
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

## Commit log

2019-08-15 Adding Schematics
2019-08-16 NoiseCode sources and wav
    [Jarmageddon_v2_yogya.ino, MiniDrone_v2.ino, attiny_Bass_v2.ino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]
